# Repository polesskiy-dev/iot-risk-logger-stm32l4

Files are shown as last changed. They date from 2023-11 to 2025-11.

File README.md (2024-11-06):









# IoT Risk Data Logger, 
## STM32L4 based

Open source & open hardware project aimed to collect environment data e.g for logistics, cold chain monitoring, last mile delivery, etc.

## Features
TODO

## Firmware docs

[Documentation: Doxygen](https://polesskiy-dev.github.io/iot-risk-logger-stm32l4/)

## Firmware structure
* enclosure - 3D models for enclosure
* hardware - schematics, PCB, BOM
* firmware/iot-risk-logger-stm32l4 - main application
  * libraries - external libraries
  * [app](https://github.com/polesskiy-dev/iot-risk-logger-stm32l4/tree/main/firmware/iot-risk-logger-stm32l4/app) - main application
    * drivers - drivers for peripherals
    * core - actors util functions, core non-threaded modules
    * config - configuration files, list of events and actors    
    * [tasks](https://github.com/polesskiy-dev/iot-risk-logger-stm32l4/tree/main/firmware/iot-risk-logger-stm32l4/app/tasks) - main threads

## Parts video 

https://github.com/polesskiy-dev/iot-risk-logger-stm32l4/assets/5185707/393b0768-925d-4c34-bb85-259de904c167

## Schematics & PCB
[Schematics PDF](hardware/docs/iot-risk-logger-stm32l4.pdf)

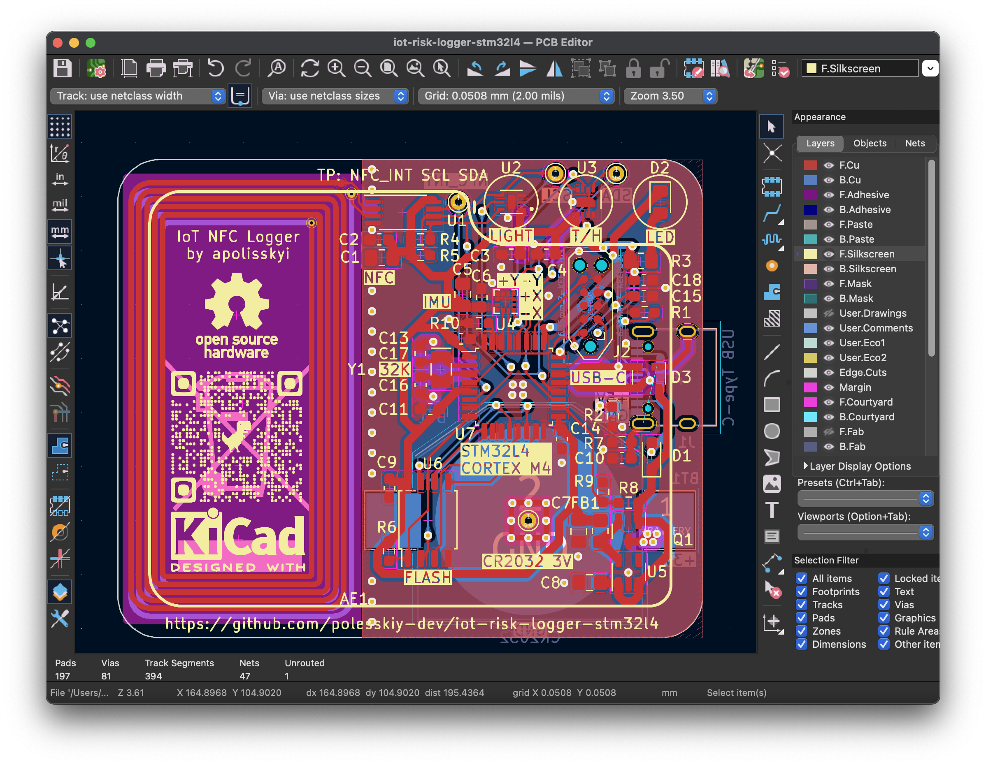
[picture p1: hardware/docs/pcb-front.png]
PCB Front

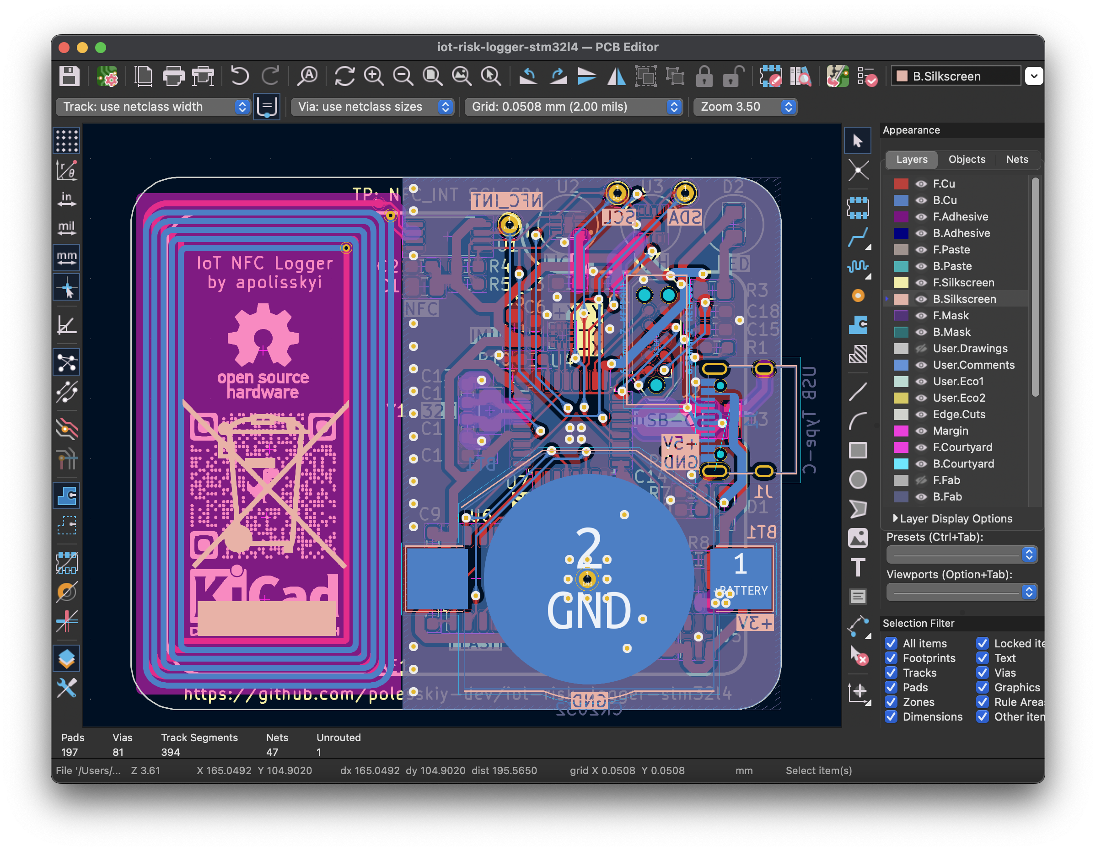
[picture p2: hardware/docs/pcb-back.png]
PCB Back


## Hardware specifications

|Item|Description|
|-|-|
| MCU | STM32L412 Cortex M4, 80MHz (48), 128K ROM, 40K RAM, TQFP32 |
| Crystal | 32.768kHz |
| Flash | QSPI 64Mbit |
| NFC | ST25DV04K |
| Temperature & Humidity | SHT30-DIS |
| Light | OPT3001 |
| IMU | LIS2DW12 |
| Power | CR2032 3V 235mAh |

## Enclosure
### Assembly

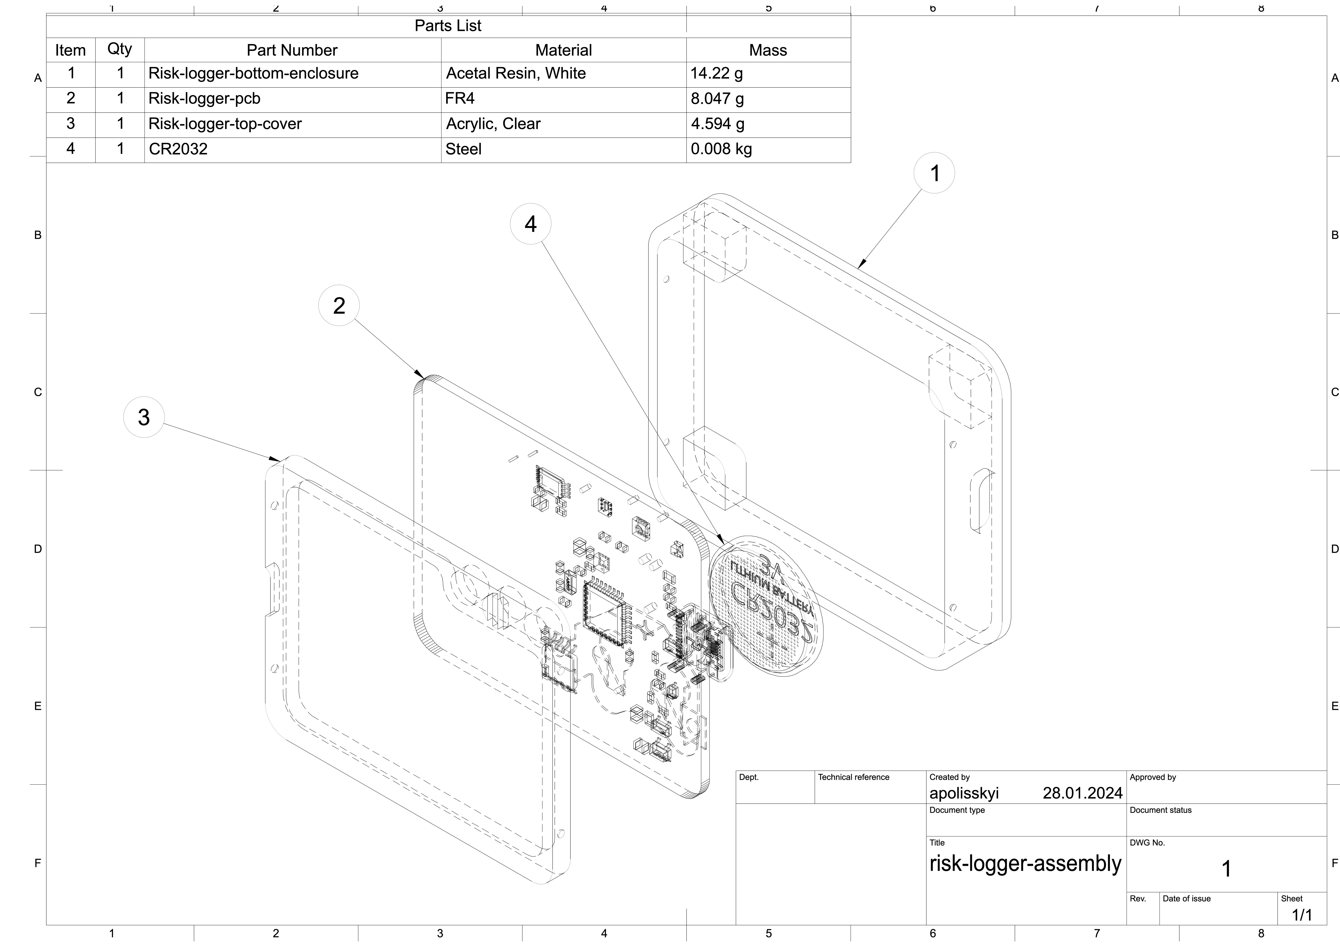
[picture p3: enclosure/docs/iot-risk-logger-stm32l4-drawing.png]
drawings


### Developed with
|||
|-|-|
| OS | MacOS, Apple Silicon |
| Schematics & PCB | KiCAD 7.0.0 |
| 3D CAD | Fusion 360 |
| Graphical MCU configure | STM32CubeMX 6.10.0 | 
| IDE | neovim, CLion |
| Hardware debug probe | J-Link EDU Mini 8.08.91 |
| Firmware debug | Segger Ozone 7.94 | 
| Firmware debug analysis | Segger SystemView 3.52 |
| Power analysis | Nordic Power Profiler Kit II |
| Oscilloscope & Logic analyzer | Digilent Analog Discovery 3 |
| Logic analyzer software | Digilent Waveforms | 

## Quick start

After clone, init submodules if you forgot

```bash
git submodule update --init --recursive
```

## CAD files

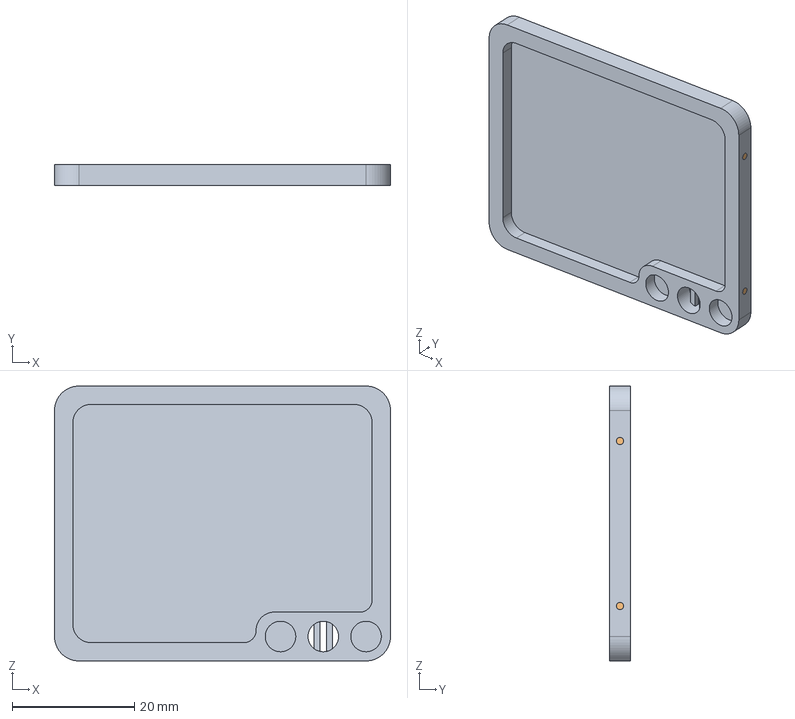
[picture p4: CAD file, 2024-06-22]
enclosure/fabrication/risk-logger-top-cover-v31.step
55.0 x 3.40 x 45.0 mm

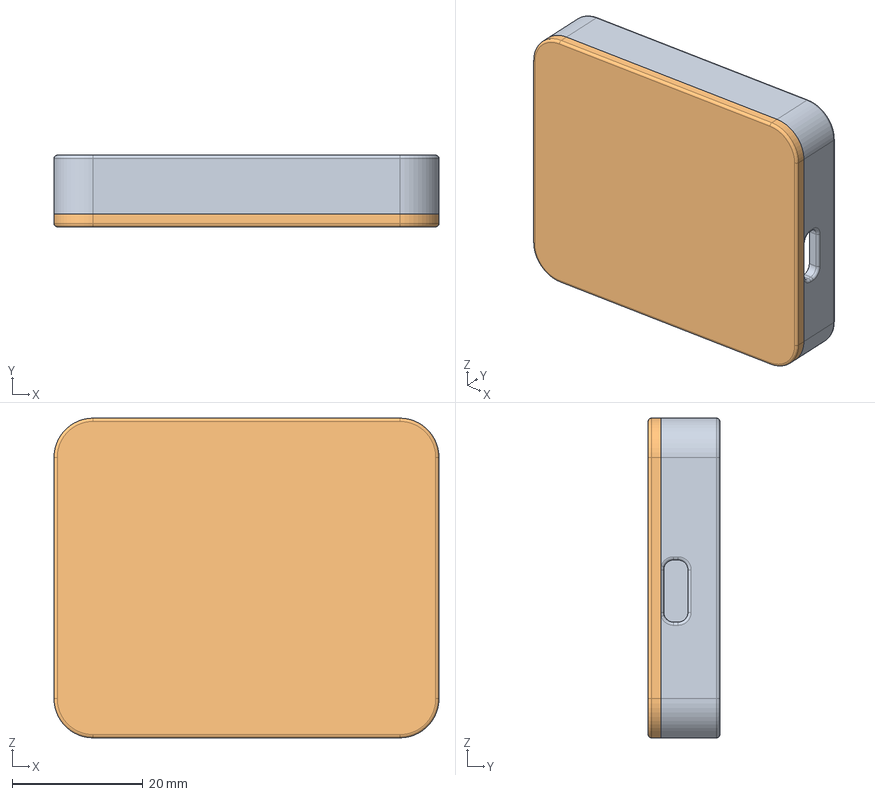
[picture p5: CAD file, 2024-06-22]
enclosure/fabrication/risk-logger-bottom-enclosure-v51.step
59.0 x 11.0 x 49.0 mm

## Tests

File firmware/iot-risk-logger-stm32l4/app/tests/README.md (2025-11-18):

# Unit Tests for IoT Risk Logger STM32L4

This directory contains unit tests for the firmware components using the Unity test framework.

## Structure

```
tests/
├── unity_framework/        # Unity test framework (submodule)
├── services/
│   └── i2c_sensors_bus/   # I2C Bus Service tests
│       └── test_sensors_bus.c
├── Makefile               # Test build system
└── README.md             # This file
```

## Prerequisites

- GCC compiler (standard C compiler)
- Make build system
- Unity test framework (automatically cloned)

## Running Tests

### Run all tests:
```bash
cd tests
make test
```

### Run specific test:
```bash
cd tests
make
./build/test_sensors_bus
```

### Clean build artifacts:
```bash
cd tests
make clean
```

## Test Coverage

### I2C Sensors Bus Service (`test_sensors_bus.c`)

Tests cover:
- ✅ Initialization with valid I2C handle
- ✅ Synchronous request handling
- ✅ Memory write operations
- ✅ Memory read operations
- ✅ HAL_BUSY retry logic configuration
- ✅ Bus error recovery (BERR)
- ✅ Arbitration lost recovery (ARLO)
- ✅ Reset function for power management
- ✅ Timeout handling
- ✅ Edge cases and error conditions

## Adding New Tests

1. Create a new test file in the appropriate subdirectory:
   ```c
   #include "unity.h"
   #include "your_module.h"
   
   void setUp(void) { /* Setup before each test */ }
   void tearDown(void) { /* Cleanup after each test */ }
   
   void test_YourFunction_Success(void) {
       TEST_ASSERT_EQUAL(expected, actual);
   }
   
   int main(void) {
       UNITY_BEGIN();
       RUN_TEST(test_YourFunction_Success);
       return UNITY_END();
   }
   ```

2. Add the test to the Makefile:
   ```makefile
   TEST_SRCS += your_module/test_your_module.c
   ```

3. Run tests:
   ```bash
   make test
   ```

## Unity Test Framework

Unity is a lightweight unit testing framework for C. Documentation: https://github.com/ThrowTheSwitch/Unity

### Common Assertions

```c
TEST_ASSERT_EQUAL(expected, actual)
TEST_ASSERT_NOT_EQUAL(expected, actual)
TEST_ASSERT_TRUE(condition)
TEST_ASSERT_FALSE(condition)
TEST_ASSERT_NULL(pointer)
TEST_ASSERT_NOT_NULL(pointer)
TEST_ASSERT_EQUAL_MEMORY(expected, actual, length)
```

## CI Integration

Tests are automatically run in the CI pipeline. See `.github/workflows/ci.yml` for configuration.

## Notes

- Tests use mocked RTOS and HAL functions to avoid hardware dependencies
- Each test file should be self-contained and independent
- Use descriptive test names following pattern: `test_ModuleName_FunctionName_Scenario`
- All tests should pass before committing code changes

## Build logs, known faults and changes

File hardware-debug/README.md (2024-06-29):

## This folder contains hardware debug tools projects.

### Segger Ozone

### Digilent Analog Discovery 3

### Nordic semi Power Profiler Kit II log

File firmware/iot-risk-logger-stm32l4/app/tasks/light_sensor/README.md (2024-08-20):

# Light Sensor Task

### Overview

### State Diagram 

<details>
  <summary>Diagram as a code</summary>
  
```plantuml
@startuml
title Light Sensor FSM
hide empty description

note "Publishes: \nGLOBAL_INITIALIZE_SUCCESS\nGLOBAL_ERROR" as N1

TURNED_OFF: Initialized, turned off\nready for commands, low power mode
CONTINUOUS_MEASURE: Device is measuring continuously\ngenerates interrupt on threshold exceed\n\nGLOBAL_WAKE_N_READ: Cron Read Measurements
OUT_OF_RANGE: Lux is out of range, limits are swapped\nreturn to measurements after lux returns in limits
ERROR: Error state\n\nGLOBAL_ERROR: Error message

[*] --> TURNED_OFF : GLOBAL_CMD_INITIALIZE

TURNED_OFF --> TURNED_OFF : SINGLE_SHOT_READ
TURNED_OFF --> TURNED_OFF : SET_LIMIT
TURNED_OFF --> CONTINUOUS_MEASURE : GLOBAL_CMD_START_CONTINUOUS_SENSING
TURNED_OFF --> ERROR : ERROR

CONTINUOUS_MEASURE --> CONTINUOUS_MEASURE : GLOBAL_WAKE_N_READ
CONTINUOUS_MEASURE --> OUT_OF_RANGE : LIMIT_INT
CONTINUOUS_MEASURE --> TURNED_OFF : TURN_OFF
CONTINUOUS_MEASURE --> ERROR : ERROR

OUT_OF_RANGE --> CONTINUOUS_MEASURE : LIMIT_INT
OUT_OF_RANGE --> OUT_OF_RANGE : CRON_READ
OUT_OF_RANGE --> TURNED_OFF : TURN_OFF
OUT_OF_RANGE --> ERROR : ERROR

ERROR --> TURNED_OFF : RECOVER (TODO)
@enduml
```
</details>

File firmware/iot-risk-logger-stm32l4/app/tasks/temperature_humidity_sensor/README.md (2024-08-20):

# Temperature & Humidity Sensor Task

### Overview

### State Diagram

<details>
  <summary>Diagram as a code</summary>

```plantuml
@startuml
title Temperature & Humidity Sensor FSM
hide empty description

note "Publishes: \nGLOBAL_INITIALIZE_SUCCESS\nGLOBAL_ERROR" as N1

IDLE: Initialized\nready for commands, low power mode
CONTINUOUS_MEASURE: Device is measuring continuously\ngenerates interrupt on threshold exceed\n\nGLOBAL_WAKE_N_READ: Cron Read Measurements
ERROR: Error state\n\nGLOBAL_ERROR: Error message

[*] --> IDLE : GLOBAL_CMD_INITIALIZE

IDLE --> IDLE : SINGLE_SHOT_READ
IDLE --> IDLE : SET_LIMIT
IDLE --> CONTINUOUS_MEASURE : GLOBAL_CMD_START_CONTINUOUS_SENSING
IDLE --> ERROR : ERROR

CONTINUOUS_MEASURE --> CONTINUOUS_MEASURE : GLOBAL_WAKE_N_READ
CONTINUOUS_MEASURE --> CONTINUOUS_MEASURE : LIMIT_INT
CONTINUOUS_MEASURE --> ERROR : ERROR

ERROR --> IDLE : RECOVER (TODO)
@enduml
```
</details>

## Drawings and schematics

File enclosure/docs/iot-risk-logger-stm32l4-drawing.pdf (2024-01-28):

4

1

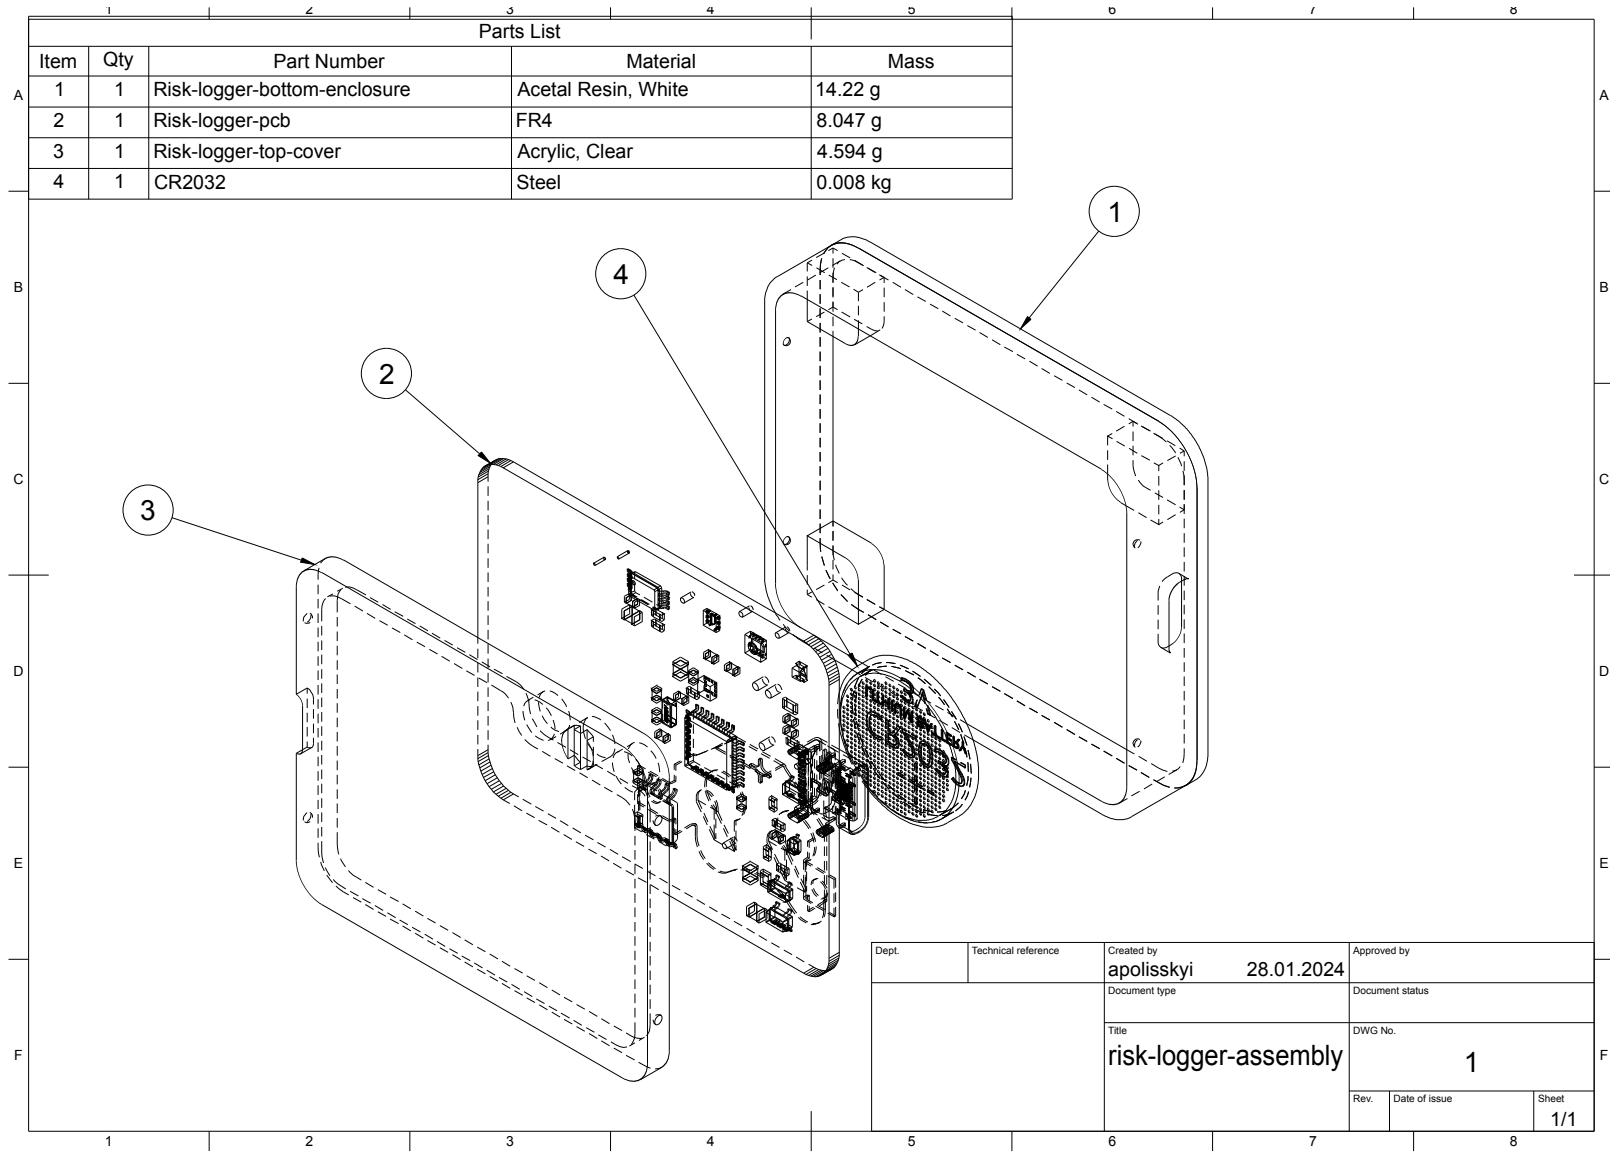
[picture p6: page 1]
Dept.; Technical reference; Created by; Approved by; Document type; Document status; Title; DWG No.; Rev.; Date of issue; Sheet; risk-logger-assembly; apolisskyi; Parts List; Item Qty; Part Number; Material; Mass; Risk-logger-bottom-enclosure; Acetal Resin, White; Risk-logger-pcb; Risk-logger-top-cover; Acrylic, Clear; Steel

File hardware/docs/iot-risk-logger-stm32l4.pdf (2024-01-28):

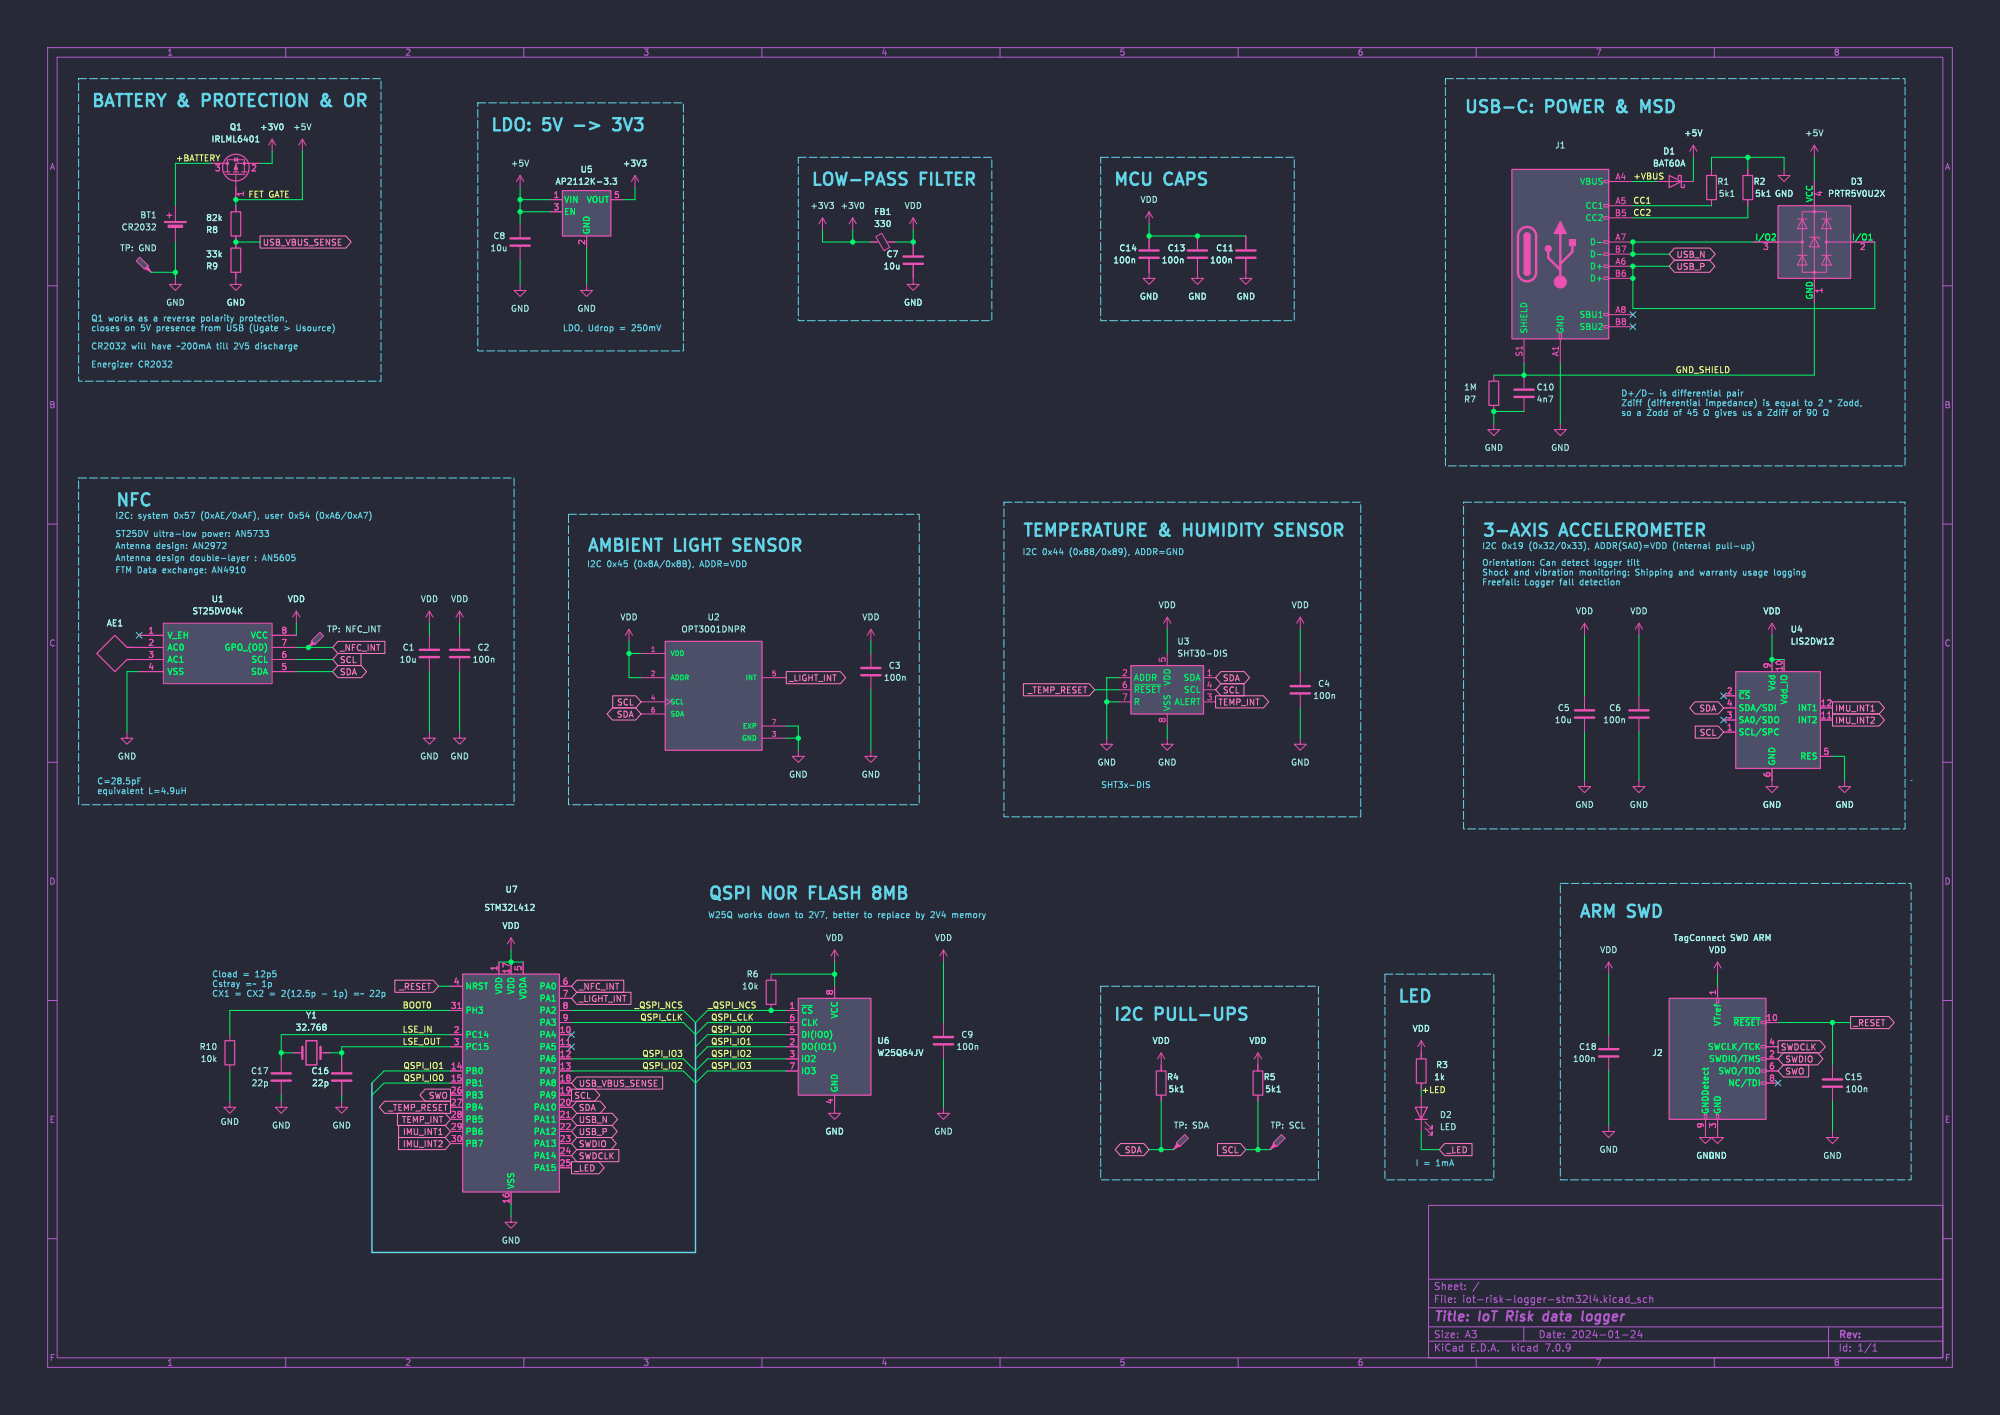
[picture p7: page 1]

W25Q works down to 2V7, better to replace by 2V4 memory QSPI NOR FLASH 8MB

1 PA4 10 PA5 11 PA6 12 PA7 13 PB0 14 PB1 15 VSS 16 VDD 17 PA8 18 PA9 19 PC14 2 PA10 20 PA11 21 PA12 22 PA13 23 PA14 24 PA15 25 PB3 26 PB4 27 PB5 28 PB6 29 PC15 3 PB7 30 PH3 31 NRST 4 VDDA
BOOT0 QSPI_IO0

Id: 1/1 Title: IoT Risk data logger File: iot-risk-logger-stm32l4.kicad_sch Sheet: /

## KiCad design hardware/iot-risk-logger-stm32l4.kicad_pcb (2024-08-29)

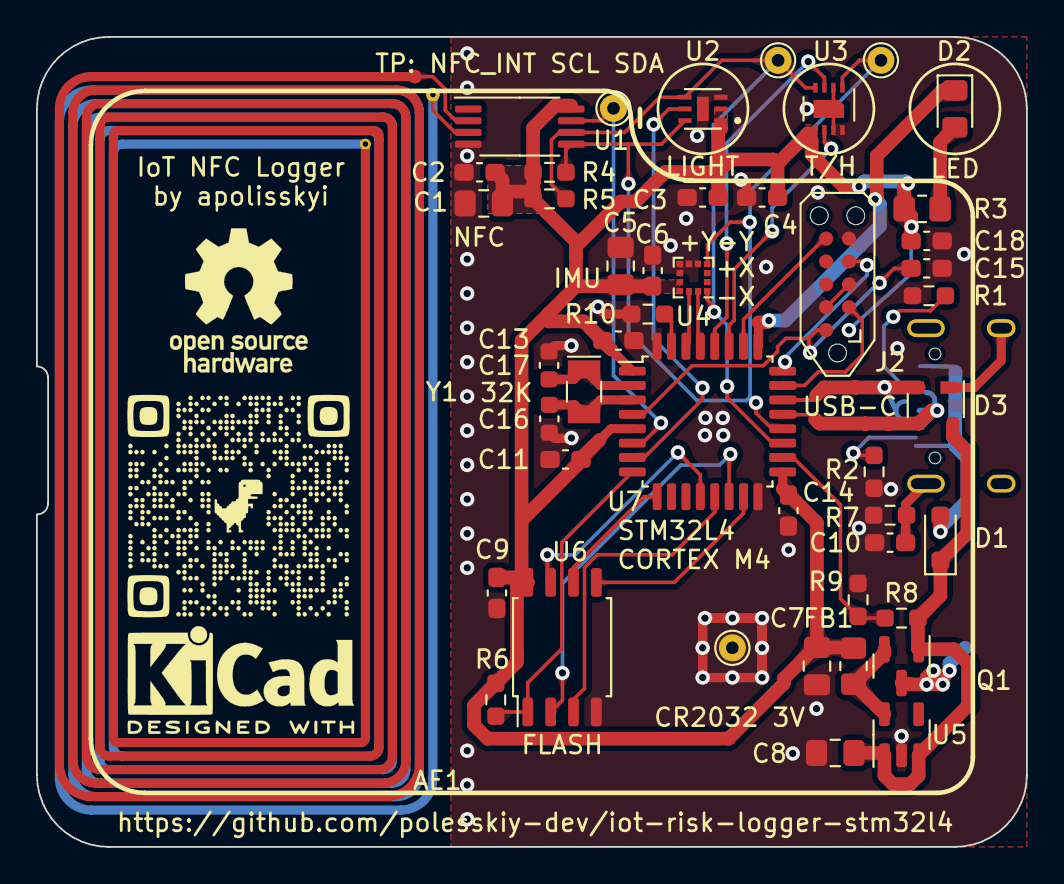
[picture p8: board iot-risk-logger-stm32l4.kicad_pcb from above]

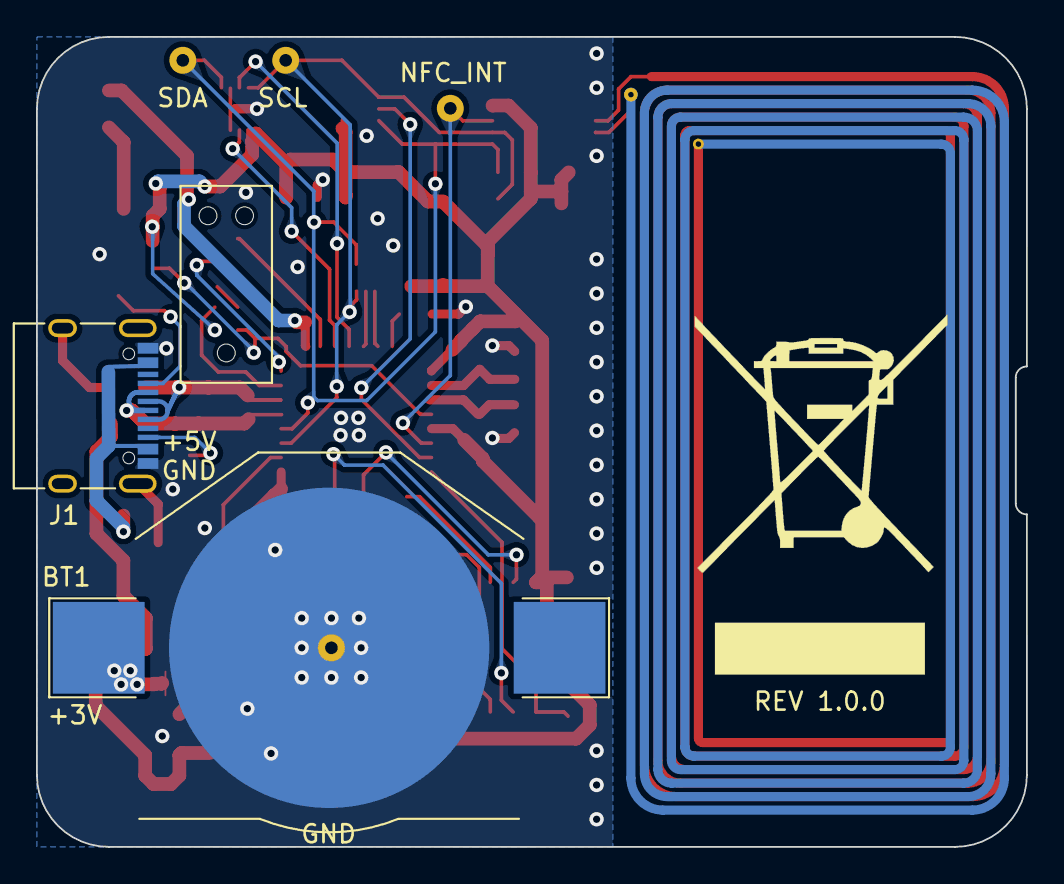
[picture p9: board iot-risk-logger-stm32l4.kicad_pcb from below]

Board: 2 copper layers, 55.0 x 45.0 mm, 51 parts (3 on the bottom side), 37 nets.

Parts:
AE1: Antenna_Loop; NFC_20x40
BT1: CR2032; BatteryHolder_Keystone_3002_1x2032
C1, C5, C7, C8: 10u; C_0805_2012Metric_Pad1.18x1.45mm_HandSolder
C2, C3, C4, C6, C9, C11, C13, C14, C15, C18: 100n; C_0603_1608Metric_Pad1.08x0.95mm_HandSolder
C10: 4n7; C_0603_1608Metric_Pad1.08x0.95mm_HandSolder
C16, C17: 22p; C_0603_1608Metric
D1: BAT60A; D_SOD-323_HandSoldering
D2: LED; LED_0805_2012Metric_Pad1.15x1.40mm_HandSolder
D3: PRTR5V0U2X; SOT-143
FB1: 330; R_0805_2012Metric_Pad1.20x1.40mm_HandSolder
J1: USB Type-C; USB_C_Receptacle_XKB_U262-16XN-4BVC11
J2: TagConnect SWD ARM; Tag-Connect_TC2050-IDC-NL_2x05_P1.27mm_Vertical_with_bottom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
Q1: IRLML6401; SOT-23
R1, R2, R4, R5: 5k1; R_0603_1608Metric_Pad0.98x0.95mm_HandSolder
R3: 1k; R_0805_2012Metric_Pad1.20x1.40mm_HandSolder
R6, R10: 10k; R_0603_1608Metric_Pad0.98x0.95mm_HandSolder
R7: 1M; R_0603_1608Metric_Pad0.98x0.95mm_HandSolder
R8: 82k; R_0603_1608Metric_Pad0.98x0.95mm_HandSolder
R9: 33k; R_0603_1608Metric_Pad0.98x0.95mm_HandSolder
REF97: WEEE-Logo_14x20mm_SilkScreen
REF98: OSHW-Logo_7.5x8mm_SilkScreen
REF99: KiCad-Logo2_5mm_SilkScreen
TP1: TP: SDA; TestPoint_THTPad_D1.5mm_Drill0.7mm
TP2: TP: SCL; TestPoint_THTPad_D1.5mm_Drill0.7mm
TP3: TP: GND; TestPoint_THTPad_D1.5mm_Drill0.7mm
TP4: TP: NFC_INT; TestPoint_THTPad_D1.5mm_Drill0.7mm
U1: ST25DV04K; TSSOP-8_4.4x3mm_P0.65mm
U2: OPT3001DNPR; SON65P200X200X65-7N
U3: SHT30-DIS; Sensirion_DFN-8-1EP_2.5x2.5mm_P0.5mm_EP1.1x1.7mm
U4: LIS2DW12; LGA-12_2x2mm_P0.5mm
U5: AP2112K-3.3; SOT-23-5
U6: W25Q64JV; SOIC-8_5.23x5.23mm_P1.27mm
U7: STM32L412; LQFP-32_7x7mm_P0.8mm
Y1: 32.768; Crystal_SMD_EuroQuartz_EQ161-2Pin_3.2x1.5mm

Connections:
+3V0: FB1.1, Q1.2 (S), U5.5 (VOUT)
+5V: C8.1, D1.1 (K), D3.4 (VCC), Q1.1 (G), R8.1, U5.1 (VIN), U5.3 (EN)
/+BATTERY: BT1.1 (+), Q1.3 (D)
/+LED: D2.2 (A), R3.2
/+VBUS: D1.2 (A), J1.A4 (VBUS), J1.A9 (VBUS), J1.B4 (VBUS), J1.B9 (VBUS)
/BOOT0: R10.2, U7.31 (PH3)
/CC1: J1.A5 (CC1), R1.2
/CC2: J1.B5 (CC2), R2.2
/GND_SHIELD: C10.1, D3.1 (GND), J1.S1 (SHIELD), J1.s1, R7.1
/LSE_IN: C17.1, U7.2 (PC14), Y1.1
/LSE_OUT: C16.1, U7.3 (PC15), Y1.2
/QSPI_CLK: U6.6 (CLK), U7.9 (PA3)
/QSPI_IO0: U6.5 (DI(IO0)), U7.15 (PB1)
/QSPI_IO1: U6.2 (DO(IO1)), U7.14 (PB0)
/QSPI_IO2: U6.3 (IO2), U7.13 (PA7)
/QSPI_IO3: U6.7 (IO3), U7.12 (PA6)
/_QSPI_NCS: R6.1, U6.1 (~CS), U7.8 (PA2)
GND: BT1.2 (-), C1.2, C2.2, C3.2, C4.2, C5.2, C6.2, C7.2, C8.2, C9.2, C10.2, C11.2, C13.2, C14.2, C15.2, C16.2, C17.2, C18.2, J1.A1 (GND), J1.A12 (GND), J1.B1 (GND), J1.B12 (GND), J2.3 (GND), J2.5 (GND), J2.9 (GNDDetect), R1.1, R2.1, R7.2, R9.2, R10.1, TP3.1, U1.4 (VSS), U2.3 (GND), U2.7 (EXP), U3.2 (ADDR), U3.7 (R), U3.8 (VSS), U3.9 (VSS), U4.5 (RES), U4.6 (GND), U4.7 (GND), U4.8 (GND), U5.2 (GND), U6.4 (GND), U7.16 (VSS), U7.32 (VSS)
IMU_INT1: U4.12 (INT1), U7.29 (PB6)
IMU_INT2: U4.11 (INT2), U7.30 (PB7)
unnamed: AE1.2, U1.2 (AC0)
unnamed: AE1.1, U1.3 (AC1)
SCL: R5.2, TP2.1, U1.6 (SCL), U2.4 (SCL), U3.4 (SCL), U4.1 (SCL/SPC), U7.19 (PA9)
SDA: R4.2, TP1.1, U1.5 (SDA), U2.6 (SDA), U3.1 (SDA), U4.4 (SDA/SDI), U7.20 (PA10)
SWDCLK: J2.4 (SWCLK/TCK), U7.24 (PA14)
SWDIO: J2.2 (SWDIO/TMS), U7.23 (PA13)
SWO: J2.6 (SWO/TDO), U7.26 (PB3)
TEMP_INT: U3.3 (ALERT), U7.28 (PB5)
USB_N: D3.3 (I/O2), J1.A7 (D-), J1.B7 (D-), U7.21 (PA11)
USB_P: D3.2 (I/O1), J1.A6 (D+), J1.B6 (D+), U7.22 (PA12)
USB_VBUS_SENSE: R8.2, R9.1, U7.18 (PA8)
VDD: C1.1, C2.1, C3.1, C4.1, C5.1, C6.1, C7.1, C9.1, C11.1, C13.1, C14.1, C18.1, FB1.2, J2.1 (VTref), R3.1, R4.1, R5.1, R6.2, U1.8 (VCC), U2.1 (VDD), U2.2 (ADDR), U3.5 (VDD), U4.9 (Vdd), U4.10 (Vdd_IO), U6.8 (VCC), U7.1 (VDD), U7.5 (VDDA), U7.17 (VDD)
_LED: D2.1 (K), U7.25 (PA15)
_LIGHT_INT: U2.5 (INT), U7.7 (PA1)
_NFC_INT: TP4.1, U1.7 (GPO_(OD)), U7.6 (PA0)
_RESET: C15.1, J2.10 (~RESET), U7.4 (NRST)
_TEMP_RESET: U3.6 (~RESET), U7.27 (PB4)

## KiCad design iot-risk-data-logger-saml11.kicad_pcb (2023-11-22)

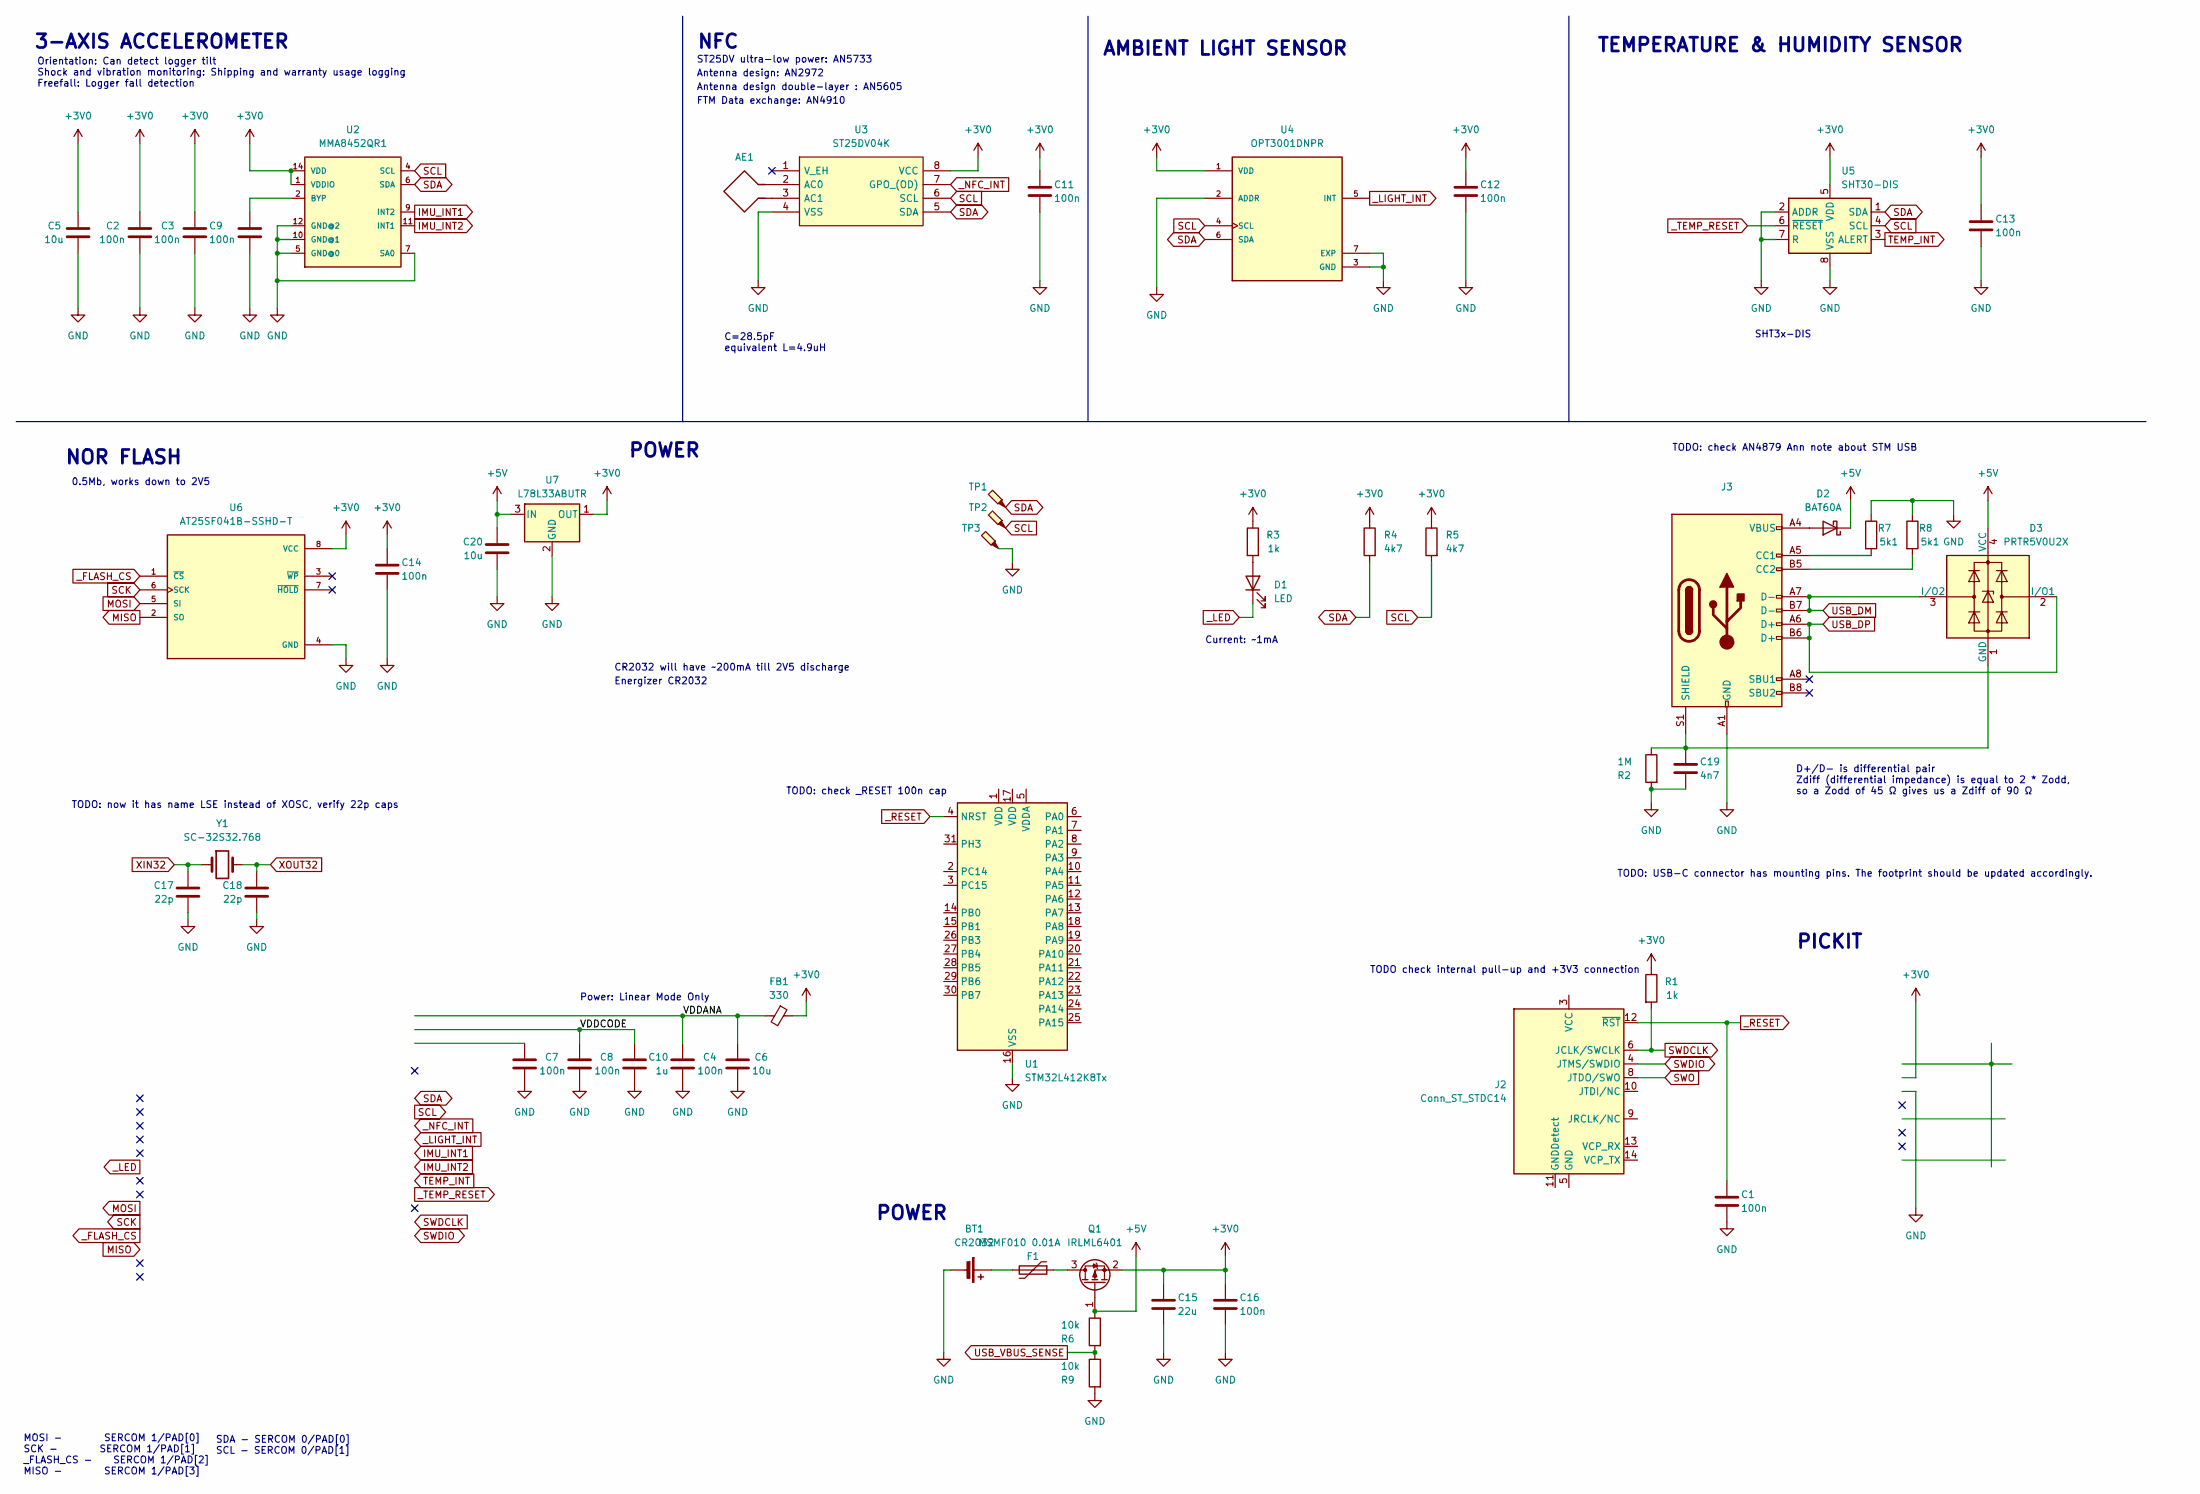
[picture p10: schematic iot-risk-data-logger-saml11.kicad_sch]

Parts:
AE1: Antenna_Loop; ANT_NFC_30x40
BT1: CR2032; BatteryHolder_Keystone_3002_1x2032; Part MY-2032-05; LCSC Part C964829
C1, C2, C3, C4, C7, C8, C9, C11, C12, C13, C14, C16: 100n; C_0805_2012Metric_Pad1.18x1.45mm_HandSolder; Part CL21B104KBCNNNC; LCSC Part C1711
C5, C6, C20: 10u; C_0805_2012Metric_Pad1.18x1.45mm_HandSolder; Part CL21A106KOQNNNE; LCSC Part C1713
C10: 1u; C_0805_2012Metric_Pad1.18x1.45mm_HandSolder; Part CL21A105KACLNNC; LCSC Part C2932475
C15: 22u; C_1206_3216Metric_Pad1.33x1.80mm_HandSolder; Part CL31A226KAHNNNE; LCSC Part C12891
C17, C18: 22p; C_0805_2012Metric_Pad1.18x1.45mm_HandSolder; Part CL21C220JBANNNC; LCSC Part C1804
C19: 4n7; C_0805_2012Metric_Pad1.18x1.45mm_HandSolder; Part CL21B472KBANNNC; LCSC Part C50131
D1: LED; LED_0805_2012Metric_Pad1.15x1.40mm_HandSolder; Part NCD0805G1; LCSC Part C84260
D2: BAT60A; D_SOD-323_HandSoldering; Part BAT60A; LCSC Part C5355496
D3: PRTR5V0U2X; SOT-143; Part PRTR5V0U2X; LCSC Part C2827688
F1: MSMF010 0.01A; Fuse_1812_4532Metric_Pad1.30x3.40mm_HandSolder; Part MF-MSMF010-2; LCSC Part C12430
FB1: 330; R_0805_2012Metric_Pad1.20x1.40mm_HandSolder; Part BLM21PG331SN1D; LCSC Part C47130
J2: Conn_ST_STDC14; PinHeader_2x07_P1.27mm_Vertical_SMD
J3: USB Type-C; USB_C_Receptacle_XKB_U262-16XN-4BVC11; Part KH-TYPE-C-16P; LCSC Part C709357
Q1: IRLML6401; SOT-23; Part IRLML6401TRPBF; LCSC Part C3034
R1, R3: 1k; R_0805_2012Metric_Pad1.20x1.40mm_HandSolder; Part RC0805FR-071KL; LCSC Part C95781
R2: 1M; R_0805_2012Metric_Pad1.20x1.40mm_HandSolder; Part RC0805FR-071ML; LCSC Part C107700
R4, R5: 4k7; R_0805_2012Metric_Pad1.20x1.40mm_HandSolder; Part RC0805FR-074K7L; LCSC Part C60816
R6, R9: 10k; R_0805_2012Metric_Pad1.20x1.40mm_HandSolder; Part RC0805FR-0710KL; LCSC Part C84376
R7, R8: 5k1; R_0805_2012Metric_Pad1.20x1.40mm_HandSolder; Part RC0805FR-075K1L; LCSC Part C84375
TP1, TP2, TP3: TestPoint_Probe; TestPoint_THTPad_D1.5mm_Drill0.7mm
U1: STM32L412K8Tx; LQFP-32_7x7mm_P0.8mm
U2: MMA8452QR1; XDCR_MMA8452QR1; Part MMA8452QR1; LCSC Part C11360
U3: ST25DV04K; TSSOP-8_4.4x3mm_P0.65mm; Part ST25DV04K-IER6T3; LCSC Part C2654816
U4: OPT3001DNPR; SON65P200X200X65-7N; Part OPT3001DNPR; LCSC Part C90462
U5: SHT30-DIS; Sensirion_DFN-8-1EP_2.5x2.5mm_P0.5mm_EP1.1x1.7mm; Part SHT30-DIS-B10KS; LCSC Part C2687423
U6: AT25SF041B-SSHD-T; SOIC-8_3.9x4.9mm_P1.27mm; Part AT25SF041B-SSHD-T; LCSC Part C5127618
U7: L78L33ABUTR; SOT-89-3_Handsoldering; Part L78L33ABUTR; LCSC Part C81362
Y1: SC-32S32.768; Crystal_SMD_EuroQuartz_EQ161-2Pin_3.2x1.5mm_HandSoldering; Part SC-32S32.768kHz20PPM12.5pF; LCSC Part C97606

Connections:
+3V0: C2.1, C3.1, C5.1, C11.1, C12.1, C13.1, C14.1, C15.1, C16.1, FB1.1, Q1.2 (S), R1.1, R3.1, R4.1, R5.1, U2.1 (VDDIO), U2.14 (VDD), U3.8 (VCC), U4.1 (VDD), U5.5 (VDD), U6.8 (VCC), U7.1 (OUT)
+5V: C20.1, D2.1 (K), D3.4 (VCC), Q1.1 (G), R6.1, U7.3 (IN)
/VDDANA: C4.1, C6.1, FB1.2
/VDDCODE: C8.1, C10.1
GND: BT1.2 (-), C1.2, C2.2, C3.2, C4.2, C5.2, C6.2, C7.2, C8.2, C9.2, C10.2, C11.2, C12.2, C13.2, C14.2, C15.2, C16.2, C17.2, C18.2, C19.2, C20.2, J3.A1 (GND), J3.A12 (GND), J3.B1 (GND), J3.B12 (GND), R2.2, R7.1, R8.1, R9.2, TP3.1, U1.16 (VSS), U1.32 (VSS), U2.5 (GND@0), U2.7 (SA0), U2.10 (GND@1), U2.12 (GND@2), U3.4 (VSS), U4.2 (ADDR), U4.3 (GND), U4.7 (EXP), U5.2 (ADDR), U5.7 (R), U5.8 (VSS), U5.9 (VSS), U6.4 (GND), U7.2 (GND)
IMU_INT1: U2.9 (INT2)
IMU_INT2: U2.11 (INT1)
MISO: U6.2 (SO)
MOSI: U6.5 (SI)
unnamed: BT1.1 (+), F1.2
unnamed: D1.2 (A), R3.2
unnamed: D2.2 (A), J3.A4 (VBUS), J3.A9 (VBUS), J3.B4 (VBUS), J3.B9 (VBUS)
unnamed: C19.1, D3.1 (GND), J3.S1 (SHIELD), R2.1
unnamed: J2.5 (GND), J2.7 (GND)
unnamed: J3.A5 (CC1), R7.2
unnamed: J3.B5 (CC2), R8.2
unnamed: F1.1, Q1.3 (D)
unnamed: C9.1, U2.2 (BYP)
unnamed: AE1.2, U3.2 (AC0)
unnamed: AE1.1, U3.3 (AC1)
SCK: U6.6 (SCK)
SCL: R5.2, TP2.1, U2.4 (SCL), U3.6 (SCL), U4.4 (SCL), U5.4 (SCL)
SDA: R4.2, TP1.1, U2.6 (SDA), U3.5 (SDA), U4.6 (SDA), U5.1 (SDA)
SWDCLK: J2.6 (JCLK/SWCLK), R1.2
SWDIO: J2.4 (JTMS/SWDIO)
SWO: J2.8 (JTDO/SWO)
TEMP_INT: U5.3 (ALERT)
USB_DM: D3.3 (I/O2), J3.A7 (D-), J3.B7 (D-)
USB_DP: D3.2 (I/O1), J3.A6 (D+), J3.B6 (D+)
USB_VBUS_SENSE: R6.2, R9.1
XIN32: C17.1, Y1.1
XOUT32: C18.1, Y1.2
_FLASH_CS: U6.1 (~CS)
_LED: D1.1 (K)
_LIGHT_INT: U4.5 (INT)
_NFC_INT: U3.7 (GPO_(OD))
_RESET: C1.1, J2.12 (~RST), U1.4 (NRST)
_TEMP_RESET: U5.6 (~RESET)

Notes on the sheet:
Current: ~1mA
POWER
CR2032 will have ~200mA till 2V5 discharge
С=28.5pF equivalent L=4.9uH
MOSI - SERCOM 1/PAD[0] SCK - SERCOM 1/PAD[1] _FLASH_CS - SERCOM 1/PAD[2] MISO - SERCOM 1/PAD[3]
TEMPERATURE & HUMIDITY SENSOR
SDA - SERCOM 0/PAD[0] SCL - SERCOM 0/PAD[1]
ST25DV ultra-low power: AN5733
NOR FLASH
TODO check internal pull-up and +3V3 connection
Antenna design double-layer : AN5605
FTM Data exchange: AN4910
3-AXIS ACCELEROMETER
D+/D- is differential pair Zdiff (differential impedance) is equal to 2 * Zodd, so a Zodd of 45 Ω gives us a Zdiff of 90 Ω
Antenna design: AN2972
TODO: now it has name LSE instead of XOSC, verify 22p caps
TODO: check _RESET 100n cap
Power: Linear Mode Only
0.5Mb, works down to 2V5
TODO: USB-C connector has mounting pins. The footprint should be updated accordingly.
AMBIENT LIGHT SENSOR
TODO: check AN4879 Ann note about STM USB
SHT3x-DIS
PICKIT
Orientation: Can detect logger tilt Shock and vibration monitoring: Shipping and warranty usage logging Freefall: Logger fall detection
Energizer CR2032
NFC

Board: 2 copper layers, 49 parts (3 on the bottom side), 23 nets, no tracks yet.

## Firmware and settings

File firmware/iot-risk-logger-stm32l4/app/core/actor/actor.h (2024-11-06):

/*!
 * @file actor.h
 * @brief Actor (Active object) pico framework
 *
 * This file contains the definitions and structures needed for the actor framework,
 * which facilitates message handling in a CMSIS-RTOS2 environment.
 *
 * @date 17/07/2024
 * @author artempolisskyi
 */

#ifndef ACTOR_H
#define ACTOR_H

#ifdef __cplusplus
extern "C" {
#endif

#include <stdio.h>

#include "cmsis_os2.h"
#include "../../config/events_list/events_list.h"
#include "../../config/actors_lookup/actors_lookup.h"

#define DEFAULT_QUEUE_SIZE 8
#define DEFAULT_QUEUE_MESSAGE_SIZE sizeof(message_t)
#define DEFAULT_TASK_STACK_SIZE_WORDS (128)

/**
 * @brief Sets the state of an inherited actor and logs the action.
 *
 * @warning inherited actor from actor_t should have a `state` member.
 *
 * @param actorPointer A pointer to inherited the actor whose state is to be set.
 *                     This should be a pointer to a struct that has a `state` member.
 * @param stateEnum    state to set
 *
 * @example
 * typedef struct {
 *  actor_t super;
 *  StateEnum_t state;
 * } My_Actor_t;
 *
 * My_Actor_t myActor;
 * TO_STATE(&myActor, FIRST_STATE);
 */
#define TO_STATE(actorPointer, stateEnum)                                     \
  do {                                                                        \
    (actorPointer)->state = (stateEnum);                                      \
    fprintf(stdout, "%lu: %s\n", (actorPointer)->super.actorId, #stateEnum);  \
  } while (0);

/**
* @brief Structure representing a message in the actor framework.
*/
typedef struct {
  event_t event;          ///< Event associated with the message
  union {
    void *ptr;            ///< Pointer to the message payload
    uint32_t value;       ///< payload value
  } payload;
  ssize_t payload_size;   ///< Size of the message payload
} message_t;

// Forward declare struct actor_t
struct actor_t;

/**
 * @brief Function pointer type for message handlers.
 *
 * @param actor Pointer to the actor that is handling the message.
 * @param message Pointer to the message to be handled.
 * @return osStatus_t Status of the message handling.
 */
typedef osStatus_t (*messageHandler_t)(struct actor_t *actor, message_t *message);

/**
 * @brief Structure representing a base actor in the actor framework.
 */
typedef struct actor_t {
  uint32_t actorId;                ///< Unique actor ID
  osThreadId_t osThreadId;         ///< CMSIS-RTOS2 Thread ID
  osMessageQueueId_t osMessageQueueId; ///< Message queue ID
  messageHandler_t messageHandler; ///< Message handler, most likely a state machine
} actor_t;

#ifdef __cplusplus
}
#endif

#endif //ACTOR_H

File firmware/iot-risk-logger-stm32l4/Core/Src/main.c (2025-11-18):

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
/* Includes ------------------------------------------------------------------*/
#include "main.h"
#include "cmsis_os.h"
#include "crc.h"
#include "lptim.h"
#include "quadspi.h"
#include "rng.h"
#include "rtc.h"
#include "usb_device.h"
#include "gpio.h"


void SystemClock_Config(void);
void MX_FREERTOS_Init(void);
/**
  * @brief  The application entry point.
  * @retval int
  */
int main(void)
{

  /* MCU Configuration--------------------------------------------------------*/

  /* Reset of all peripherals, Initializes the Flash interface and the Systick. */
  HAL_Init();

  /* Configure the system clock */
  SystemClock_Config();

  /* Initialize all configured peripherals */
  MX_GPIO_Init();
  MX_RTC_Init();
  MX_LPTIM1_Init();
  MX_QUADSPI_Init();
  MX_CRC_Init();
  MX_RNG_Init();
  /* USER CODE BEGIN 2 */
  BSP_I2C1_Init(); // init i2c

//  RETARGET_Init(); // init stdio, debug
  SEGGER_RTT_Init();
  INFO_LED_Init();

  #ifdef DEBUG
//      __HAL_RCC_DBGMCU_CLK_ENABLE();    // Enable clocks for Debug register
      __HAL_DBGMCU_FREEZE_TIM6();       // Freeze TIM6 during debugging
      __HAL_DBGMCU_FREEZE_RTC();        // Freeze RTC during debugging
      __HAL_DBGMCU_FREEZE_WWDG();       // Freeze WWDG during debugging
      HAL_DBGMCU_EnableDBGStopMode();   // Enable the Debug Module during STOP mode
  #endif
  /* USER CODE END 2 */

  /* Init scheduler */
  osKernelInitialize();  /* Call init function for freertos objects (in cmsis_os2.c) */
  MX_FREERTOS_Init();

  /* Start scheduler */
  osKernelStart();

  /* We should never get here as control is now taken by the scheduler */

  /* Infinite loop */
  /* USER CODE BEGIN WHILE */
  while (1)
  {
    /* USER CODE END WHILE */

    /* USER CODE BEGIN 3 */
  }
  /* USER CODE END 3 */
}

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
/**
  * @brief  Period elapsed callback in non blocking mode
  * @note   This function is called  when TIM6 interrupt took place, inside
  * HAL_TIM_IRQHandler(). It makes a direct call to HAL_IncTick() to increment
  * a global variable "uwTick" used as application time base.
  * @param  htim : TIM handle
  * @retval None
  */
void HAL_TIM_PeriodElapsedCallback(TIM_HandleTypeDef *htim)
{
  if (htim->Instance == TIM6)
  {
    HAL_IncTick();
  }
}

/**
  * @brief  This function is executed in case of error occurrence.
  * @retval None
  */
void Error_Handler(void)
{
  /* USER CODE BEGIN Error_Handler_Debug */
  /* User can add his own implementation to report the HAL error return state */
  __disable_irq();
  while (1)
  {
  }
  /* USER CODE END Error_Handler_Debug */
}
#ifdef USE_FULL_ASSERT
/**
  * @brief  Reports the name of the source file and the source line number
  *         where the assert_param error has occurred.
  * @param  file: pointer to the source file name
  * @param  line: assert_param error line source number
  * @retval None
  */
void assert_failed(uint8_t *file, uint32_t line)
{
  /* USER CODE BEGIN 6 */
  /* User can add his own implementation to report the file name and line number,
     ex: printf("Wrong parameters value: file %s on line %d\r\n", file, line) */
  /* USER CODE END 6 */
}
#endif /* USE_FULL_ASSERT */

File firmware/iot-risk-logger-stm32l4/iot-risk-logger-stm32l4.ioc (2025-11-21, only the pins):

Mcu.UserName=STM32L412KBTx
PA0-CK_IN.GPIO_Label=NFC_INT_N
PA0-CK_IN.Signal=GPXTI0
PA1.GPIO_Label=LIGHT_INT_N
PA1.Signal=GPXTI1
PA10.GPIO_Label=I2C1_SDA_SENS
PA10.Signal=I2C1_SDA
PA11.Signal=USB_DM
PA12.Signal=USB_DP
PA2.Signal=QUADSPI_BK1_NCS
PA3.Signal=QUADSPI_CLK
PA4.Signal=GPIO_Analog
PA5.Signal=GPIO_Analog
PA6.Signal=QUADSPI_BK1_IO3
PA7.Signal=QUADSPI_BK1_IO2
PA8.GPIO_Label=USB_VBUS_SENSE
PA8.Signal=GPXTI8
PA9.GPIO_Label=I2C1_SCL_SENS
PA9.Signal=I2C1_SCL
PB0.Signal=QUADSPI_BK1_IO1
PB1.Signal=QUADSPI_BK1_IO0
PB5.GPIO_Label=TEMP_INT
PB5.Signal=GPXTI5
PB6.GPIO_Label=IMU_INT1
PB6.Signal=GPXTI6
PB7.GPIO_Label=IMU_INT2
PB7.Signal=GPXTI7

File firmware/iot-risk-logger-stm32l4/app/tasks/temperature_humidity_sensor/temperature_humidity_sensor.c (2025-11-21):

/*!
 * @file temperature_humidity_sensor.c
 * @brief implementation of temperature_humidity_sensor
 *
 * Detailed description of the implementation file.
 *
 * @date 17/07/2024
 * @author artempolisskyi
 */

#include "temperature_humidity_sensor.h"

static osStatus_t handleTHSensorFSM(TH_SENS_Actor_t *this, message_t *message);
/** states handlers */
static osStatus_t handleInit(TH_SENS_Actor_t *this, message_t *message);
static osStatus_t handleIdle(TH_SENS_Actor_t *this, message_t *message);
static osStatus_t handleContinuousMeasure(TH_SENS_Actor_t *this, message_t *message);
static osStatus_t handleError(TH_SENS_Actor_t *this, message_t *message);
/** utils */
static uint32_t delayMs(uint32_t ms);

extern actor_t* ACTORS_LOOKUP_SystemRegistry[MAX_ACTORS];

/**
 * @brief Temperature & Humidity Sensor actor struct
 * @extends actor_t
 */
TH_SENS_Actor_t TH_SENS_Actor = {
        .super = {
                .actorId = TEMPERATURE_HUMIDITY_SENSOR_ACTOR_ID,
                .messageHandler = (messageHandler_t) handleTHSensorFSM,
                .osMessageQueueId = NULL,
                .osThreadId = NULL,
        },
        .state = TH_SENS_NO_STATE,
        .rawTemperature = 0x0000,    ///< raw temperature value
        .rawHumidity = 0x0000,       ///< raw humidity value
};

// task description required for static task creation
uint32_t thSensorTaskBuffer[DEFAULT_TASK_STACK_SIZE_WORDS];
StaticTask_t thSensorTaskControlBlock;
const osThreadAttr_t thSensorTaskDescription = {
        .name = "thSensorTask",
        .cb_mem = &thSensorTaskControlBlock,
        .cb_size = sizeof(thSensorTaskControlBlock),
        .stack_mem = &thSensorTaskBuffer[0],
        .stack_size = sizeof(thSensorTaskBuffer),
        .priority = (osPriority_t) osPriorityNormal,
};

/**
 * @brief Initializes the Temperature and Humidity Sensor task.
 * @return {actor_t*} - pointer to the actor base struct
 */
actor_t* TH_SENS_TaskInit(void) {
  TH_SENS_Actor.super.osMessageQueueId = osMessageQueueNew(DEFAULT_QUEUE_SIZE, DEFAULT_QUEUE_MESSAGE_SIZE, &(osMessageQueueAttr_t){
          .name = "thSensorQueue"
  });
  TH_SENS_Actor.super.osThreadId = osThreadNew(TH_SENS_Task, NULL, &thSensorTaskDescription);

  return (actor_t*) &TH_SENS_Actor;
 }

/**
 * @brief Temperature & Humidity Sensor task
 * Waits for message from the queue and proceed it in FSM
 * Enters ERROR state if message handling failed
 */
void TH_SENS_Task(void *argument) {
  (void) argument; // Avoid unused parameter warning
  message_t msg;

  #ifdef DEBUG
    fprintf(stdout, "Task %s started\n", thSensorTaskDescription.name);
  #endif

  for (;;) {
    // Wait for messages from the queue
    if (osMessageQueueGet(TH_SENS_Actor.super.osMessageQueueId, &msg, NULL, osWaitForever) == osOK) {
      osStatus_t handleMessageStatus = TH_SENS_Actor.super.messageHandler((actor_t *) &TH_SENS_Actor, &msg);

      if (handleMessageStatus != osOK) {
        #ifdef DEBUG
          fprintf(stderr,  "%s: Error handling event %u in state %ul\n", thSensorTaskDescription.name, msg.event, TH_SENS_Actor.state);
        #endif

        osMessageQueueId_t evManagerQueue = ACTORS_LOOKUP_SystemRegistry[EV_MANAGER_ACTOR_ID]->osMessageQueueId;
        osMessageQueuePut(evManagerQueue, &(message_t){GLOBAL_ERROR, .payload.value = TEMPERATURE_HUMIDITY_SENSOR_ACTOR_ID}, 0, 0);
        TO_STATE(&TH_SENS_Actor, TH_SENS_STATE_ERROR);
      }
    }
  }
}

static osStatus_t handleTHSensorFSM(TH_SENS_Actor_t *this, message_t *message) {
  switch (this->state) {
    case TH_SENS_NO_STATE:
      return handleInit(this, message);
    case TH_SENS_IDLE_STATE:
      return handleIdle(this, message);
    case TH_SENS_CONTINUOUS_MEASURE_STATE:
      return handleContinuousMeasure(this, message);
    case TH_SENS_STATE_ERROR:
      // TODO implement error handling
      return handleError(this, message);
    default:
      return osOK;
  }
}

static osStatus_t handleInit(TH_SENS_Actor_t *this, message_t *message) {
  if (GLOBAL_CMD_INITIALIZE == message->event) {
    // provide IO functions to the sensor driver
    osStatus_t ioStatus = SHT3x_InitIO(TH_SENS_I2C_ADDRESS, SensorsBus_Send, SensorsBus_Recv, delayMs, NULL);

    if (ioStatus != osOK) return osError;

    // reset the sensor by pulling down _TEMP_RESET, at least 1uS duration required
    HAL_GPIO_WritePin(TEMP_RESET_N_GPIO_Port, TEMP_RESET_N_Pin, GPIO_PIN_RESET);
    osDelay(1);
    HAL_GPIO_WritePin(TEMP_RESET_N_GPIO_Port, TEMP_RESET_N_Pin, GPIO_PIN_SET);
    osDelay(10); // wait for sensor to be ready after reset

    // read sensor ID
    uint32_t sht3xId = 0x00000000;
    ioStatus = SHT3x_ReadDeviceID(&sht3xId);

    if (ioStatus != osOK) return osError;

    #ifdef DEBUG
      fprintf(stdout, "SHT3x ID: %lu\n", sht3xId);
    #endif

    // publish to event manager that the sensor is initialized
    osMessageQueueId_t evManagerQueue = ACTORS_LOOKUP_SystemRegistry[EV_MANAGER_ACTOR_ID]->osMessageQueueId;
    osMessageQueuePut(evManagerQueue, &(message_t){GLOBAL_INITIALIZE_SUCCESS, .payload.value = TEMPERATURE_HUMIDITY_SENSOR_ACTOR_ID}, 0, 0);

    #ifdef DEBUG
      fprintf(stdout, "Temperature & Humidity sensor %u initialized\n", TEMPERATURE_HUMIDITY_SENSOR_ACTOR_ID);
    #endif

    TO_STATE(this, TH_SENS_IDLE_STATE);
  }

  return osOK;
}

static osStatus_t handleIdle(TH_SENS_Actor_t *this, message_t *message) {
  osStatus_t  ioStatus = osOK;

  switch (message->event) {
    case GLOBAL_CMD_START_CONTINUOUS_SENSING:
      ioStatus = SHT3x_PeriodicAcquisitionMode(SHT3x_START_MEASUREMENT_0_5_MPS_LOW_REPEATABILITY_CMD_ID);
      if (ioStatus != osOK) return osError;

      TO_STATE(this, TH_SENS_CONTINUOUS_MEASURE_STATE);
      return osOK;
    case TH_SENS_START_SINGLE_SHOT_READ:
      // TODO run single-shot measurement
//      #ifdef DEBUG
//        fprintf(stdout, "Raw: temperature: %d humidity %d\n", this->rawTemperature, this->rawHumidity);
//      #endif

      TO_STATE(this, TH_SENS_IDLE_STATE);
      return osOK;
    default:
      return osOK;
  }
}
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

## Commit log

2023-11-16 Initial commit with clean KiCAD project
    [iot-risk-data-logger-saml11.kicad_pcb, iot-risk-data-logger-saml11.kicad_sch]
2023-11-17 DRAFT: schematics, initial PCB placement overview
    [iot-risk-data-logger-saml11.kicad_pcb, iot-risk-data-logger-saml11.kicad_sch]
2023-11-22 DRAFT:replace saml11 by stm32l412, add USB
    [iot-risk-data-logger-saml11.kicad_pcb, iot-risk-data-logger-saml11.kicad_sch]
2023-11-30 rename to iot-risk-logger-stm32l4 and andd harwware/
    [iot-risk-logger-stm32l4.kicad_pcb, iot-risk-logger-stm32l4.kicad_sch]
2023-11-30 CubeMX: draft initial config, KiCad: pins assignment draft
    [iot-risk-logger-stm32l4.kicad_sch]
2023-12-03 CubeMX: set pins
    [iot-risk-logger-stm32l4.kicad_pcb, iot-risk-logger-stm32l4.kicad_sch]
2023-12-08 CubeMX: add qspi
    [iot-risk-logger-stm32l4.kicad_pcb, iot-risk-logger-stm32l4.kicad_sch]
2023-12-12 PCB: first version of layout
    [iot-risk-logger-stm32l4.kicad_pcb, iot-risk-logger-stm32l4.kicad_sch]
2024-01-21 Schematics: assign all BOM parts
    [iot-risk-logger-stm32l4.kicad_pcb, iot-risk-logger-stm32l4.kicad_sch]
2024-01-24 PCB: prefinal board
    [iot-risk-logger-stm32l4.kicad_pcb, iot-risk-logger-stm32l4.kicad_sch]
2024-01-25 PCB: prefinal static routing
    [iot-risk-logger-stm32l4.kicad_pcb]
2024-01-25 PCB: routed
    [iot-risk-logger-stm32l4.kicad_pcb]
2024-01-25 BOM: export and cleanup
2024-01-27 README: add dev tools table
    [iot-risk-logger-stm32l4.kicad_pcb]
2024-01-28 README: update schematics
    [iot-risk-logger-stm32l4.kicad_pcb, iot-risk-logger-stm32l4.kicad_sch]
2024-02-07 PCB: paint in different colours
    [iot-risk-logger-stm32l4.kicad_pcb, iot-risk-logger-stm32l4.kicad_sch]
2024-06-22 PCB: add colours and board extraction cutout
    [iot-risk-logger-stm32l4-B_Cu.gbl, iot-risk-logger-stm32l4-B_Cu.gbr, iot-risk-logger-stm32l4-B_Mask.gbr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]
2024-06-27 :feat: feat(info LED) create a helloworld LED blinking task
2024-06-27 :wrench: feat(NFC) configure X-CUBE-NFC in CubeMX for custom board
2024-06-29 :heavy_plus_sign: add hardware-debu/ folder with debug probes projects
2024-06-30 :star: feat(NFC) basic NFC init, flash LED on GPO interrupt
2024-07-02 :star: feat(NFC) draft read MB length, MB data to buffer, buffer debug printf
2024-07-18 :construction: new(temperature-humidity sensor) add TH Sensor initial task structure
2024-07-18 :arrow_up: deps(sht3x) add senserion sht3x sensor library
2024-07-28 :construction: feat(TH Sensor) draft sht3x library integration
2024-07-28 :hatching_chick: feat(Light Sensor) initial files infrastructure
2024-07-29 :star: feat(Light Sensor) initial task's infrastructure
2024-07-30 :start: feat(OPT3001) Driver
2024-07-30 :start: feat(OPT3001) Light Sensor init function
2024-07-30 :star: Light Sensor Single shot read
2024-08-04 :star: feat(Light Sensor) implement transition handlers, State diagram docs
2024-08-04 :star: feat(SHT3x) create drivers interface
2024-08-07 :shirt: refactor(RTT) replace RTT printf by SystemView
    [nfc.c, nfc_handlers.c, temperature_humidity_sensor.c]
2024-08-08 :star: feat(Light Sensor) add simple log state transitions capability
2024-08-12 :arrow_up: deps(STM32Cube MCU Package) upgrade to 1.18.1
2024-08-12 :star: feat(INFO_LED) switch from task to non-task functionality
2024-08-12 :star: feat(retarget) proper fprintf utilization with SystemView debug printf
2024-08-13 :star: feat(stop2) fix sleep mode unexpected interrupts
    [iot-risk-logger-stm32l4.ioc, nfc.c, nfc_handlers.c]
2024-08-14 :hatching_chick: feat(power mode manager) initial creation
2024-08-16 :star: feat(light sensor) integrate global init receive
2024-08-16 :construction: wip(th sensor) start implementing the interface functions
2024-08-17 :star: feat(th sensor) io init, crc8, ID read
2024-08-17 :star: feat(th sensor) implement continuous measurements
2024-08-19 :star: feat(i2c) add mutex so light and th sensors are not conflicting
2024-08-20 :hatching_chick: feat(w255q) driver initialization
2024-08-20 :pencil: docs(sensors) prettify FSM description
2024-08-20 :pencil: docs(sensors, memory) add some basic Doxygen comments to core handlers
2024-08-20 :lipstick: update(debug) printf on DEBUG defined
2024-08-29 :star: feat(w25q) basic driver implementation
    [iot-risk-logger-stm32l4.kicad_pcb]
2024-09-03 :star: feat(w25q) NOR flash driver finished
2024-11-06 :construction: wip(MEMORY) implemented settings read/write flow
2024-12-11 :construction: feat(NFC) pass CMDs to event manager. :boom: hard faults on NFC settings read flow, for now
2025-10-04 :construction: wip(POWER) disabple perepherial on sleep
2025-11-18 :star: feat(temperature sensor): increase init delay, few other chores
2025-11-21 :sparkles: feat(IMU):initialization, FIFO reading, data averaging and saving to memory on CRON
    DFT-27
    :sparkles: feat(IMU): add basic configuraton, initial data read on FIFO watermark and freefall events
    :bug:fix(IMU):i2c1 resource access initialization throughout mutex
    :sparkles:feat(IMU): add draft averaging on 16 samples ready, averaging on writing to memory on CRON
    [gpio_ext_interrupts.c, imu.c, imu.h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]

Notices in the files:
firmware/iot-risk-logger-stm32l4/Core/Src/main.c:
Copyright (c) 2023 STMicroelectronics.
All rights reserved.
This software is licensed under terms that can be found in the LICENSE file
